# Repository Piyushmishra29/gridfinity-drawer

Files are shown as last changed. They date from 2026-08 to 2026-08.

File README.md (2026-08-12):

# Gridfinity Drawer Baseplates — 15 in × 20.5 cm

Custom [Gridfinity](https://gridfinity.xyz/) baseplates sized to exactly fill a drawer measuring **15 in × 20.5 cm (381 × 205 mm)**.

The drawer holds a **9 × 4 grid** of standard 42 mm Gridfinity squares. Since that's too wide for a single print on a Bambu (256 × 256 mm) bed, it's split into two plates that sit side by side.

## Files

| File | Grid | Printed size | Notes |
|---|---|---|---|
| `baseplate_left_5x4_fitted.stl` | 5 × 4 | 212.5 × 204.5 mm | Extra margin on left + back edges |
| `baseplate_right_4x4_fitted.stl` | 4 × 4 | 168.0 × 204.5 mm | Extra margin on right + back edges |
| `baseplate_5x4.stl` | 5 × 4 | 210 × 168 mm | Plain grid, no drawer padding |
| `baseplate_4x4.stl` | 4 × 4 | 168 × 168 mm | Plain grid, no drawer padding |

The `_fitted` plates use the fit-to-drawer padding so the pair fills the drawer edge-to-edge (380.5 × 204.5 mm total — 0.5 mm clearance so they don't jam). The plain plates are included in case you want the grid-only version for a different drawer.

## Print settings

- **Style**: thin baseplate (5 mm tall), no magnet or screw holes — sits loose in the drawer
- No supports needed, prints flat as-is
- 2 walls, 15% infill is plenty
- Any material works; PLA is fine for drawer use

## How they were generated

Rendered with [gridfinity-rebuilt-openscad](https://github.com/kennetek/gridfinity-rebuilt-openscad) by kennetek (MIT licensed):

```bash
# left plate (5×4, padded to 212.5 × 204.5)
openscad -o baseplate_left_5x4_fitted.stl \
  -D gridx=5 -D gridy=4 -D style_plate=0 -D style_hole=0 \
  -D distancex=212.5 -D distancey=204.5 -D fitx=-1 -D fity=1 \
  gridfinity-rebuilt-baseplate.scad

# right plate (4×4, padded to 168 × 204.5)
openscad -o baseplate_right_4x4_fitted.stl \
  -D gridx=4 -D gridy=4 -D style_plate=0 -D style_hole=0 \
  -D distancex=168 -D distancey=204.5 -D fitx=1 -D fity=1 \
  gridfinity-rebuilt-baseplate.scad
```

Gridfinity was created by [Zack Freedman](https://www.youtube.com/watch?v=ra_9zU-mnl8); any standard Gridfinity bin (Printables, MakerWorld, etc.) snaps onto these plates.

## Drawer 3 — 454.5 × 386 mm, magnetic (A1 mini)

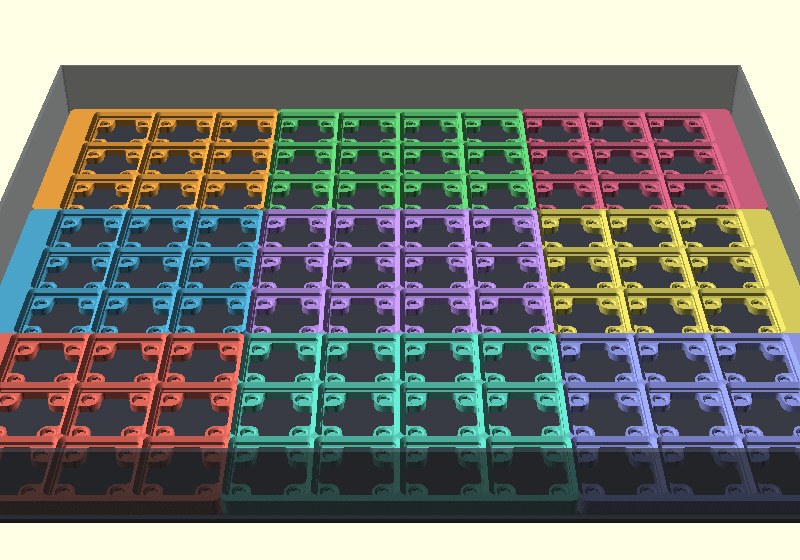
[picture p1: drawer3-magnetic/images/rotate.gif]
Assembled


| | |
|---|---|
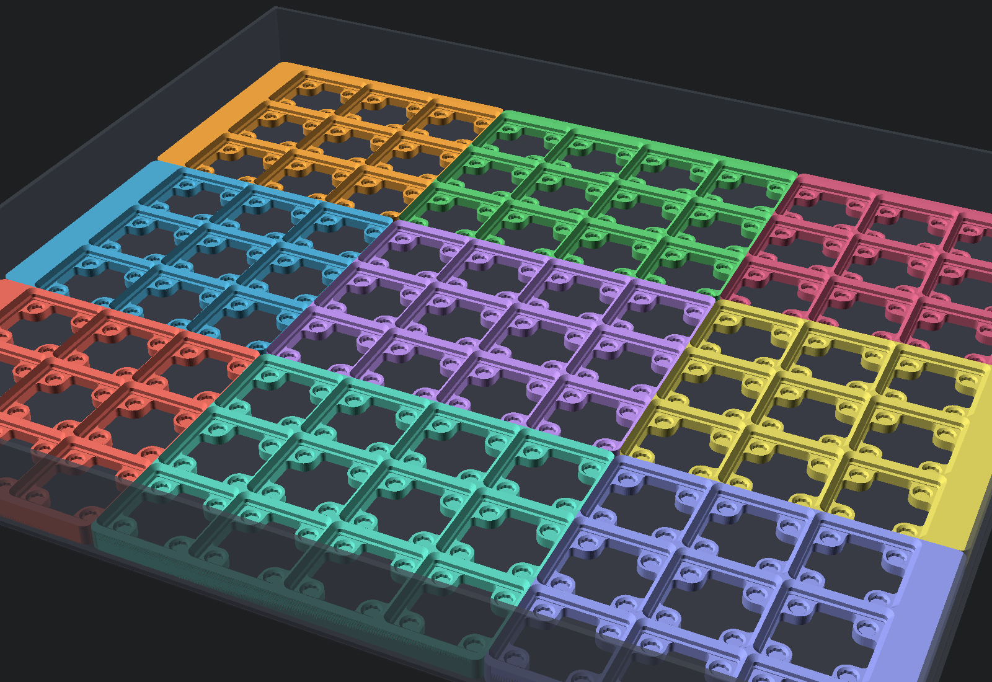
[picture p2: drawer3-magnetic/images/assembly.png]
Assembly
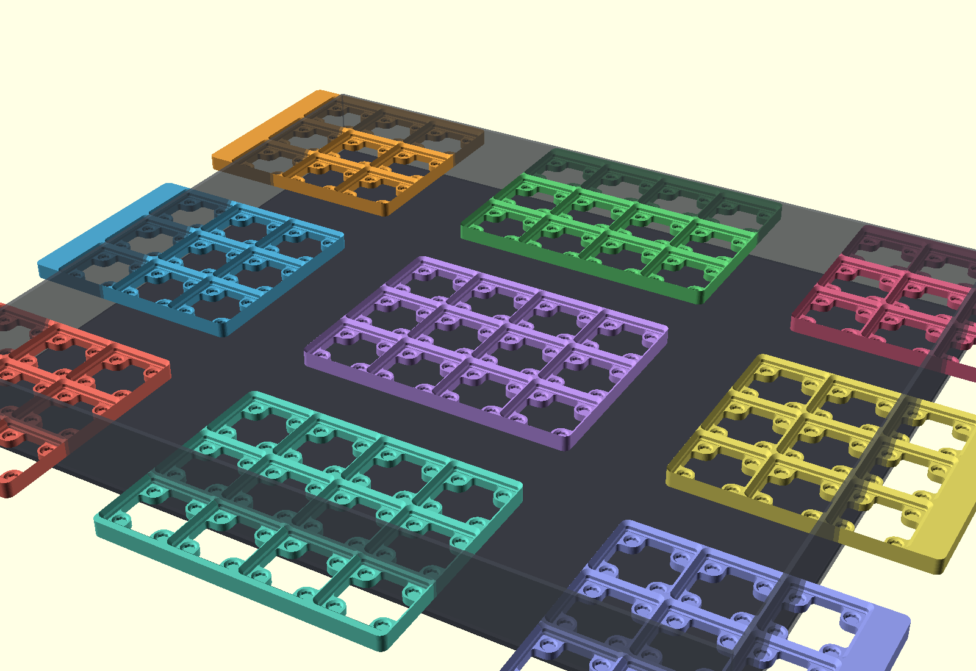
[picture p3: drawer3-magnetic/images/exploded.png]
Exploded
|  |  |
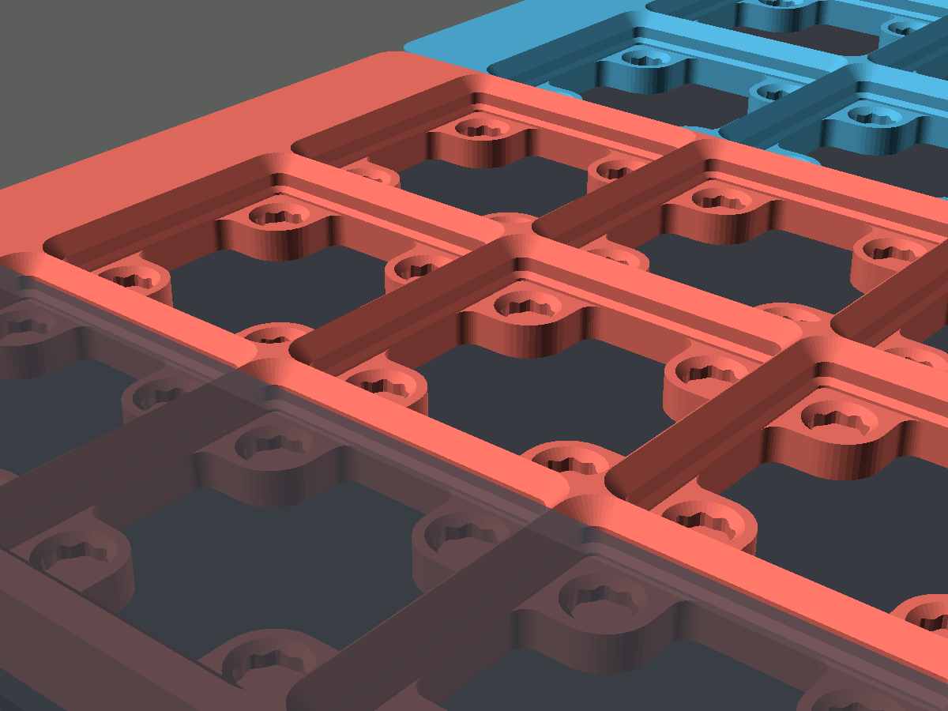
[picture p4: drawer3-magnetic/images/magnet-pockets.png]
Magnet pockets — crush ribs, no glue needed
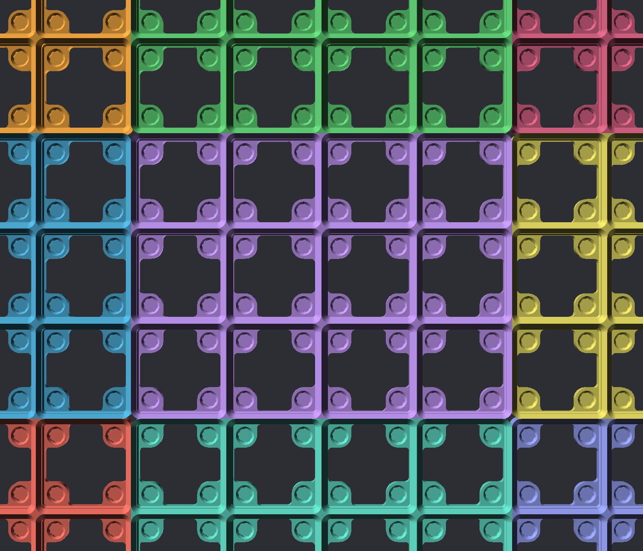
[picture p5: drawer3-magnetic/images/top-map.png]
Top placement map
|  |  |

`drawer3-magnetic/` — **10 × 9 grid** (90 squares) split into **9 plates** that each fit an A1 mini (180 mm bed). Skeletonized style, 9.35 mm tall, with pockets for **6 × 2 mm round magnets** (crush ribs + chamfer — press fit, no glue). Assembled size 454.0 × 385.5 mm (0.5 mm clearance).

| Position | Grid | Size (mm) |
|---|---|---|
| Front/Back Left+Right (4 pcs) | 3×3 | 143 × 129.75 |
| Front/Back Mid (2 pcs) | 4×3 | 168 × 129.75 |
| Mid Left+Right (2 pcs) | 3×3 | 143 × 126 |
| Mid Mid (1 pc) | 4×3 | 168 × 126 |

`GRIDFINITY_MAG_DRAWER_A1MINI.3mf` — all 9 pieces as 9 plates in one A1-mini-native project. Full magnet population = 4 per square = **360 magnets**; populating only under bins that need hold is normal.

Generated with gridfinity-rebuilt-openscad: `style_plate=2` (skeletonized), `enable_magnet=true`, fitted with `distancex/y` + `fitx/y` per piece (outer pieces carry the drawer padding: +17 mm on left/right columns, +3.75 mm on front/back rows).

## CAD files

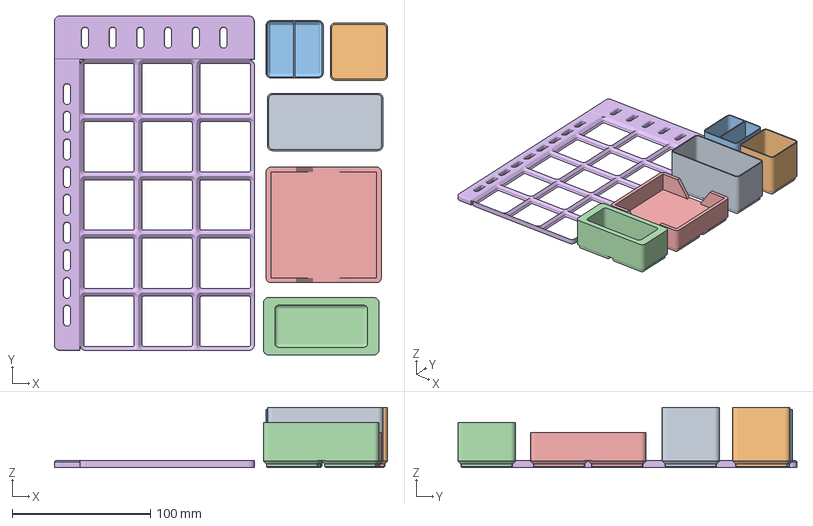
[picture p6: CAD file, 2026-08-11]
drawer2-print.3mf
240.8 x 244.8 x 43.5 mm
Tub 1x2.step
Tub 1x1.step
Tub Split 1x1.step
LED lamp 1x2.step
Post It Note Holder 2x2.step
drawer2_baseplate_3x5_skadis

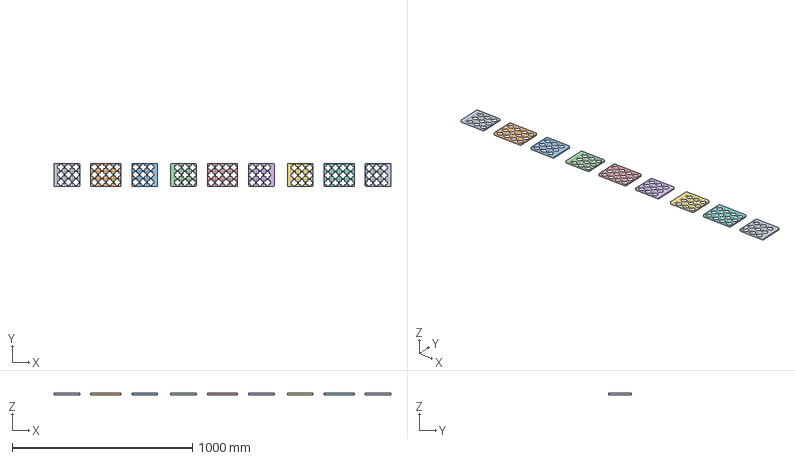
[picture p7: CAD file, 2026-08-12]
drawer3-magnetic/GRIDFINITY_MAG_DRAWER_A1MINI.3mf
1871.0 x 129.8 x 9.35 mm
FrontLeft_3x3
FrontMid_4x3
FrontRight_3x3
MidLeft_3x3
MidMid_4x3
MidRight_3x3
BackLeft_3x3
BackMid_4x3
BackRight_3x3

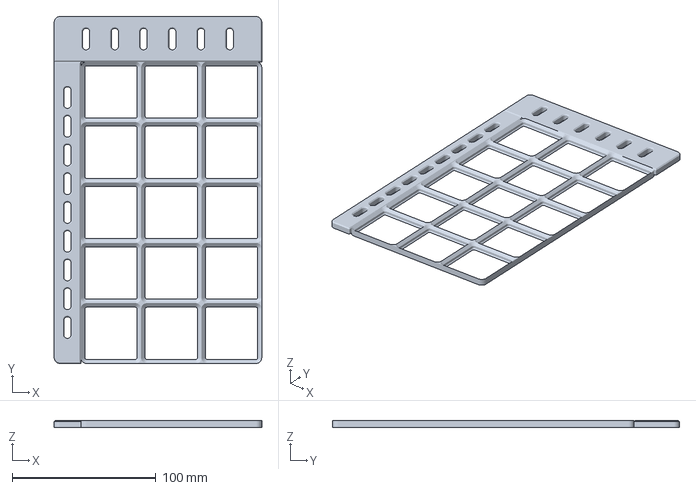
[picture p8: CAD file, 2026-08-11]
gridfinity-drawer2.3mf
144.5 x 241.5 x 5.00 mm

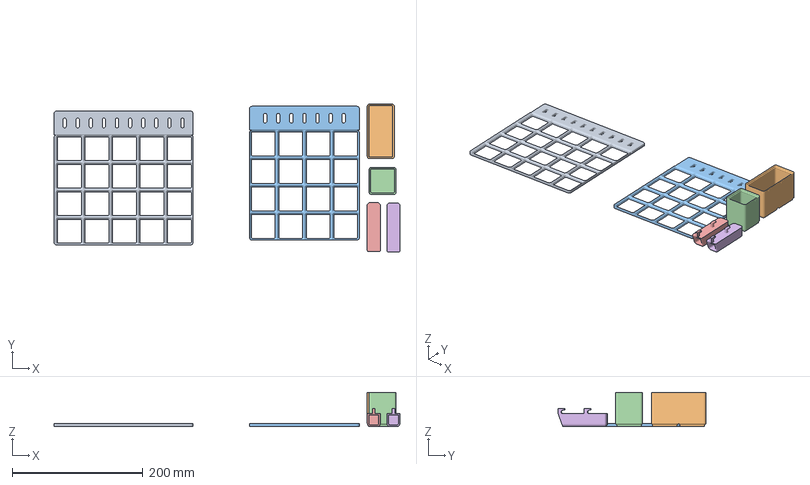
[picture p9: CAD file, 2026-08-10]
gridfinity-drawer-skadis.3mf
528.4 x 225.9 x 52.5 mm
baseplate_left_5x4_skadis.stl
bin_2x1_7u.stl
baseplate_right_4x4_skadis.stl
bin_1x1_7u.stl
skadis_deburring_organizer.stl x 2

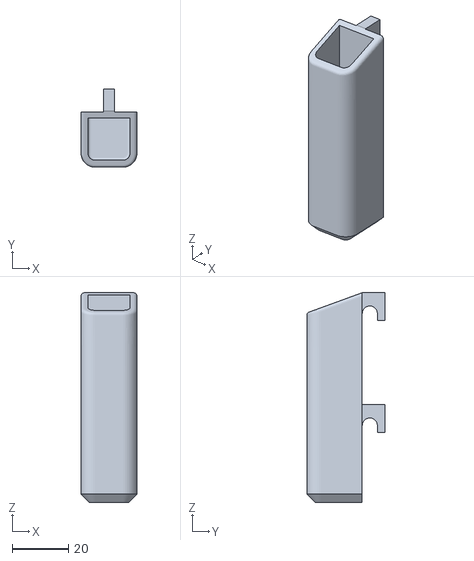
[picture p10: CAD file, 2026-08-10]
skadis_deburring_organizer.stl
20.0 x 28.0 x 75.0

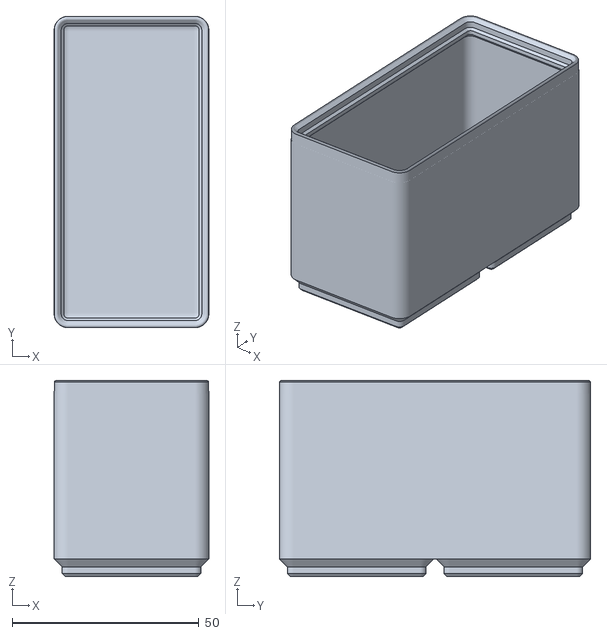
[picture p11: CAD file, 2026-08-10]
bin_2x1_7u.stl
41.5 x 83.5 x 52.5

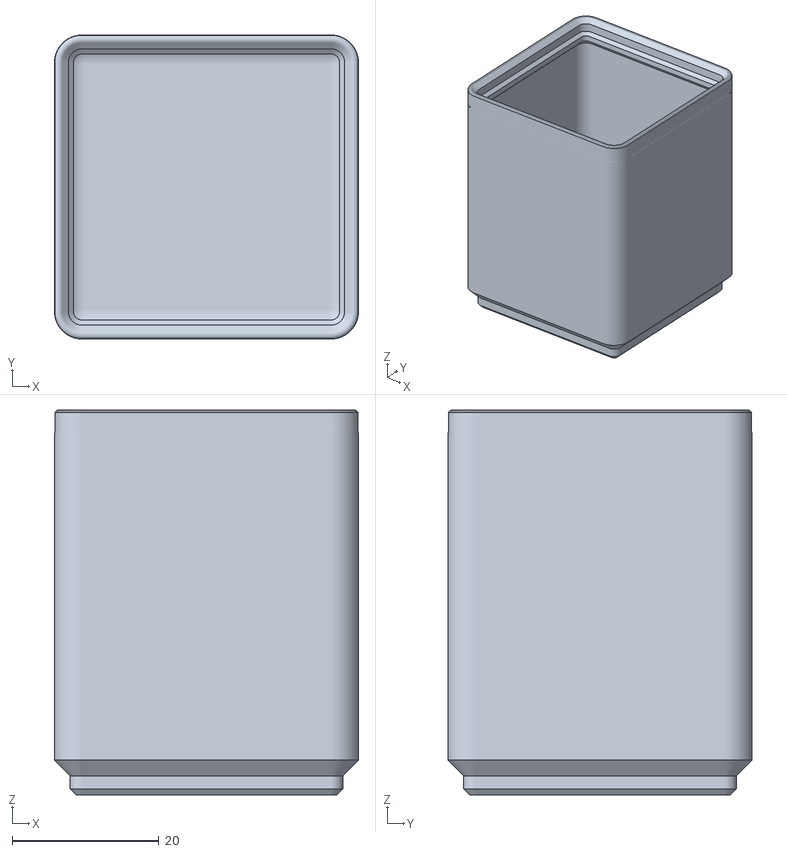
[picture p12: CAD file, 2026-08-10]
bin_1x1_7u.stl
41.5 x 41.5 x 52.5

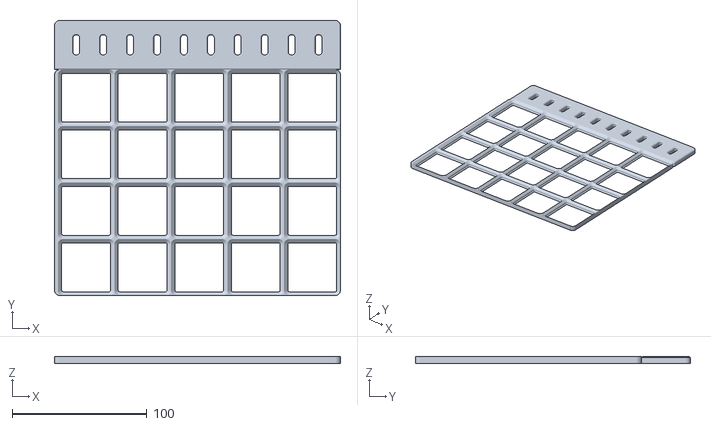
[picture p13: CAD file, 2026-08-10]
baseplate_left_5x4_skadis.stl
212.5 x 204.5 x 5.00

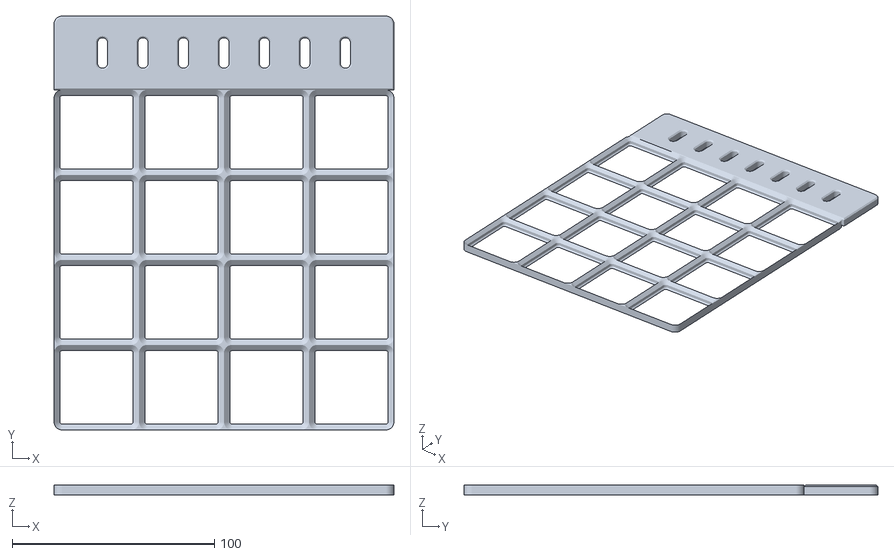
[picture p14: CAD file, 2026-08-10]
baseplate_right_4x4_skadis.stl
168.0 x 204.5 x 5.00

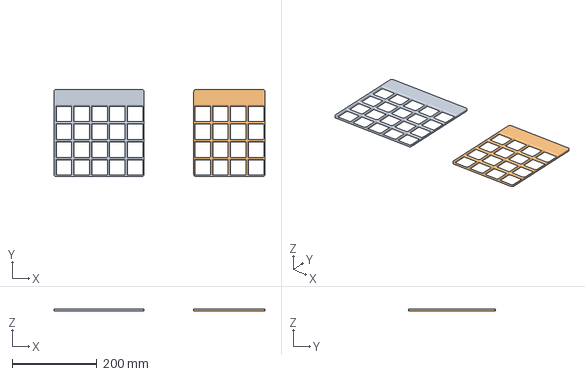
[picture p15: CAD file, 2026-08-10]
gridfinity-drawer.3mf
497.5 x 204.5 x 5.00 mm
baseplate_left_5x4_fitted.stl
baseplate_right_4x4_fitted.stl

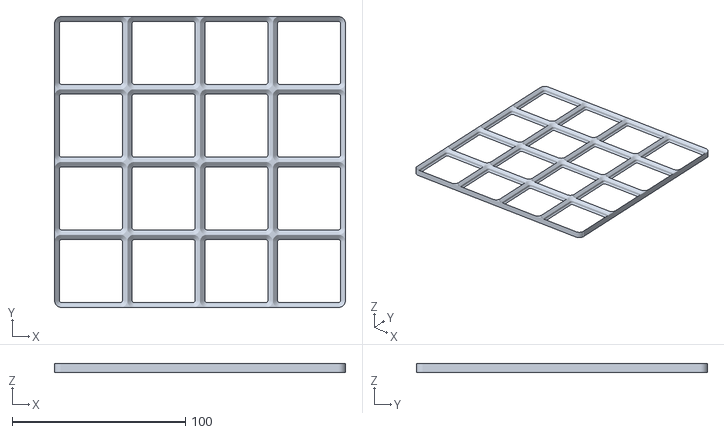
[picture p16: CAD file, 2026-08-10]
baseplate_4x4.stl
168.0 x 168.0 x 5.00

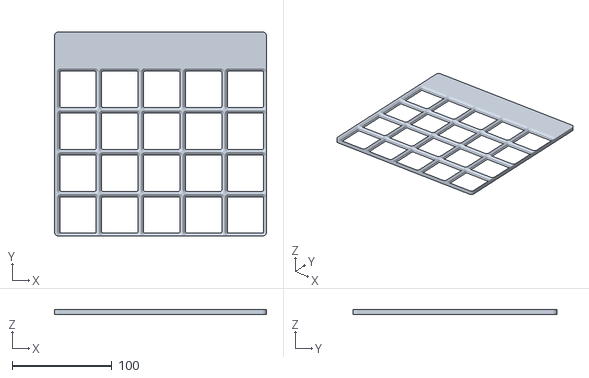
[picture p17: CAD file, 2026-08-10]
baseplate_left_5x4_fitted.stl
212.5 x 204.5 x 5.00

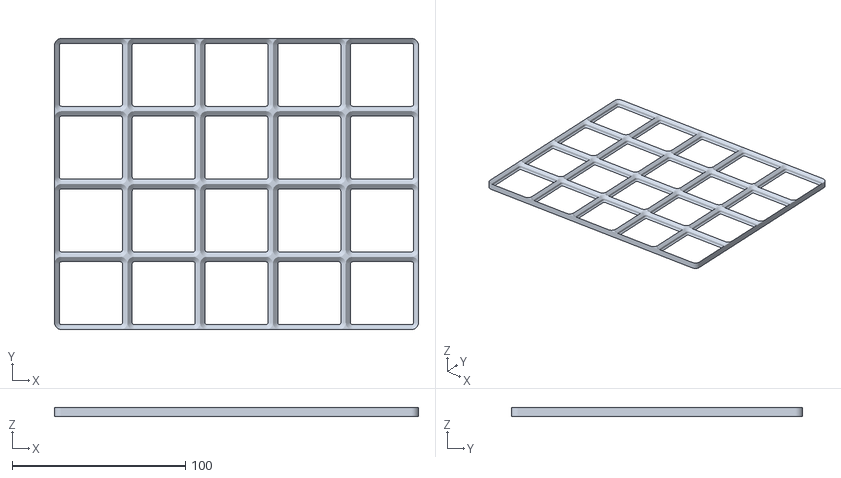
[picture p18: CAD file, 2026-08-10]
baseplate_5x4.stl
210.0 x 168.0 x 5.00

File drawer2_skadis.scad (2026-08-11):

// Drawer 2: 145 x 242 mm space -> 3x5 gridfinity + flush Skadis L-border.
// Grid plate (native, 126 x 210, x +-63 y +-105 z 0..5) + back strip (31.5) + left strip (18.5).
// Flush 5mm, slots cut through, edges softened like drawer 1.

include <gridfinity-rebuilt-baseplate.scad>

deck = 5;
cham = 0.8;
corner_r = 4;
slot_w = 5; slot_l = 15;
pitch = 20;

// plate outline: x -81.5..63, y -105..136.5
bx0 = -81.5; bx1 = 63; by0 = -105; by1 = 136.5;
gx0 = -63; gy1 = 105;               // grid region edges adjoining the strips

module obround2d(cx, cy) {
    translate([cx, cy]) hull() {
        translate([0, -(slot_l - slot_w)/2]) circle(d = slot_w, $fn = 48);
        translate([0,  (slot_l - slot_w)/2]) circle(d = slot_w, $fn = 48);
    }
}

module slot_cut(cx, cy) {
    translate([0, 0, -1]) linear_extrude(deck + 2) obround2d(cx, cy);
    hull() {
        translate([0, 0, deck - cham]) linear_extrude(0.01) obround2d(cx, cy);
        translate([0, 0, deck + 0.01]) linear_extrude(0.01) offset(r = cham) obround2d(cx, cy);
    }
}

// convex 2D rect with selected corners rounded, chamfer-extruded via hull
module soft_prism(shape_pts_rect, round_corners) {
    // shape passed via children: children(0) = 2D shape
    hull() {
        linear_extrude(deck - cham) children(0);
        translate([0, 0, deck - 0.01]) linear_extrude(0.01) offset(r = -cham) children(0);
    }
}

module back_strip2d() {   // x bx0..bx1, y gy1..by1; round both back corners
    hull() {
        translate([bx0, gy1]) square([bx1 - bx0, by1 - gy1 - corner_r]);
        translate([bx0 + corner_r, by1 - corner_r]) circle(r = corner_r, $fn = 64);
        translate([bx1 - corner_r, by1 - corner_r]) circle(r = corner_r, $fn = 64);
    }
}

module left_strip2d() {   // x bx0..gx0, y by0..gy1; round front-left corner
    hull() {
        translate([bx0, by0 + corner_r]) square([gx0 - bx0, gy1 - by0 - corner_r]);
        translate([bx0 + corner_r, by0 + corner_r]) circle(r = corner_r, $fn = 64);
        translate([bx0 + corner_r, by0]) square([gx0 - bx0 - corner_r, gy1 - by0]);
    }
}

// slot positions
back_yc = (gy1 + by1) / 2;                          // 120.75
back_xs = [for (i = [0:5]) -59.25 + i * pitch];     // 6 slots across the back
left_xc = (bx0 + gx0) / 2;                          // -72.25
left_ys = [for (i = [0:8]) -80 + i * pitch];        // 9 slots down the left

difference() {
    union() {
        soft_prism() back_strip2d();
        soft_prism() left_strip2d();
    }
    for (x = back_xs) slot_cut(x, back_yc);
    for (y = left_ys) slot_cut(left_xc, y);
}

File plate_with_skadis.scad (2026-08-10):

// Gridfinity baseplate (native, grid-only depth) + Skadis rail butted on the back edge.
// Pass through -D: gridx, gridy, style_plate, style_hole, distancex, fitx (library params)
// plus X0/X1 (plate x extents), NSLOTS. Plate y back edge = gridy*42/2, z 0..5.

include <gridfinity-rebuilt-baseplate.scad>

X0 = -1; X1 = 1;    // -D overridden
NSLOTS = 1;

rail_d = 36.5;      // fills drawer depth beyond the grid
wall = 2;
deck = 5;           // Skadis board thickness at the slots — accessory clips need this
deck_d = 25;        // deck is a band around the slots, not the full strip
cavity_h = 6;       // hook clearance under the deck
slot_w = 5; slot_l = 15;
pitch = 20;
rib = 1.6;

py = gridy * 42 / 2;          // plate back edge (84 for gridy=4)
yc = py + rail_d / 2;
sx0 = (X0 + X1)/2 - (NSLOTS - 1) * pitch / 2;

corner_r = 4;       // matches the gridfinity plate outer corner
cham = 0.8;         // 45-degree top-edge chamfer, matches the gridfinity look

module obround2d(x) {
    translate([x, yc]) hull() {
        translate([0, -(slot_l - slot_w)/2]) circle(d = slot_w, $fn = 48);
        translate([0,  (slot_l - slot_w)/2]) circle(d = slot_w, $fn = 48);
    }
}

// strip footprint: square front edge (mates the plate), R4 back corners
module strip2d() {
    hull() {
        translate([X0, py]) square([X1 - X0, rail_d - corner_r]);
        translate([X0 + corner_r, py + rail_d - corner_r]) circle(r = corner_r, $fn = 64);
        translate([X1 - corner_r, py + rail_d - corner_r]) circle(r = corner_r, $fn = 64);
    }
}

// slot cutter with a chamfered mouth
module skadis_slot(x) {
    translate([0, 0, -1]) linear_extrude(deck + 2) obround2d(x);
    hull() {
        translate([0, 0, deck - cham]) linear_extrude(0.01) obround2d(x);
        translate([0, 0, deck + 0.01]) linear_extrude(0.01) offset(r = cham) obround2d(x);
    }
}

// rail (implicit union with the library's plate output):
// FLUSH variant — solid 5mm strip level with the plate, slots cut through,
// top perimeter chamfered and back corners rounded to match the gridfinity edges.
// Standard Skadis hooks cannot mount (no cavity behind); slots serve custom
// screw/twist-anchor accessories designed for a floor-backed board.
difference() {
    hull() {
        linear_extrude(deck - cham) strip2d();
        translate([0, 0, deck - 0.01]) linear_extrude(0.01) offset(r = -cham) strip2d();
    }
    for (i = [0 : NSLOTS - 1]) skadis_slot(sx0 + i * pitch);
}

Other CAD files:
drawer2_baseplate_3x5_fitted.stl
drawer2_baseplate_3x5_skadis.stl
baseplate_right_4x4_fitted.stl

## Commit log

2026-08-10 Gridfinity baseplates for 15in x 20.5cm drawer (9x4 grid, split for Bambu bed)
    [baseplate_4x4.stl, baseplate_5x4.stl, baseplate_left_5x4_fitted.stl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]
2026-08-10 Add Bambu Studio project: both plates in one 3MF (A1, two build plates)
    [gridfinity-drawer.3mf]
2026-08-10 Add Skadis rail variant: raised slotted rail fills the back strip
    13mm rail, 5mm deck, 5x15mm obround slots at 20mm pitch, 8mm hook
    cavity, ribs for bridging. Two-plate Bambu project included.
    [baseplate_left_5x4_skadis.stl, baseplate_right_4x4_skadis.stl, gridfinity-drawer-skadis.3mf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]
2026-08-10 Slim the Skadis rail: 11mm tall, 2mm walls, 25mm deck band, 6mm cavity
    20% less solid volume overall (~45% off the rail itself); deck stays
    5mm at the slots for accessory clip compatibility.
    [baseplate_left_5x4_skadis.stl, baseplate_right_4x4_skadis.stl, gridfinity-drawer-skadis.3mf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]
2026-08-10 Flush Skadis strip: 5mm, level with the plate, slots cut through
    Per Piyush's call: seamless look over hook compatibility; slots serve
    custom floor-backed anchor accessories.
    [baseplate_left_5x4_skadis.stl, baseplate_right_4x4_skadis.stl, gridfinity-drawer-skadis.3mf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]
2026-08-10 Soften Skadis strip edges to match gridfinity: R4 back corners, 0.8mm top chamfer, chamfered slot mouths
    [baseplate_left_5x4_skadis.stl, baseplate_right_4x4_skadis.stl, gridfinity-drawer-skadis.3mf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]
2026-08-10 Add 1x1 and 2x1 gridfinity bins (7U, ~5cm) on plate 2
    [bin_1x1_7u.stl, bin_2x1_7u.stl, gridfinity-drawer-skadis.3mf]
2026-08-10 Add Skadis deburring organizer to plate 2 free space (preserves saved layout)
    [gridfinity-drawer-skadis.3mf, skadis_deburring_organizer.stl]
2026-08-10 Color scheme: yellow gridfinity plates (filament 1), gray bins and organizers (filament 2); P2S profile per Piyush's save
    [gridfinity-drawer-skadis.3mf]
2026-08-10 Disable prime tower
    [gridfinity-drawer-skadis.3mf]
2026-08-10 Pin prime tower off as explicit preset override so the GUI stops re-enabling it
    [gridfinity-drawer-skadis.3mf]
2026-08-11 Drawer 2 (145x242mm): 3x5 baseplate with flush Skadis L-border, single-piece P2S project
    6 slots across the 31.5mm back strip, 9 down the 18.5mm left strip,
    same flush 5mm + softened edges as drawer 1.
    [drawer2_baseplate_3x5_fitted.stl, drawer2_baseplate_3x5_skadis.stl, drawer2_skadis.scad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]
2026-08-11 Drawer 2 project: merge 53-piece all-in-one gridfinity accessory set (11 plates) + baseplate on plate 12
2026-08-11 drawer2-print: plate 12 extracted as standalone print file, yellow baseplate + white boxes
    [drawer2-print.3mf]
2026-08-11 drawer2-print: prime tower off, pinned as preset override
    [drawer2-print.3mf]
2026-08-11 drawer2-print: single filament, everything white, no swaps
    [drawer2-print.3mf]
2026-08-12 Drawer 3: magnetic 10x9 baseplates for 454.5x386mm drawer, 9 A1-mini plates
    [GRIDFINITY_MAG_DRAWER_A1MINI.3mf]
2026-08-12 Drawer 3: renders + rotating GIF (assembly, exploded, magnet pockets, top map)
